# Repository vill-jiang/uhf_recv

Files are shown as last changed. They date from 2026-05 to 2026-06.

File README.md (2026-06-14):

# MT06xx UHF无线音频接收机项目

## 项目概述

这是一个基于STC8H1K17单片机+KT0656M的UHF无线话筒接收机项目,双通道接收,旋转编码器输入,菜单设置,OLED128x64输出.

## 项目起因

事情的起因是在小黄鱼捡垃圾捡到了便宜的UHF话筒,但是没有适配的接收机,所以把话筒拆开发现是 SH88F4051AX + KT0646M 的方案,刮了I2C的线路并且捕获了芯片初始化和设置通道的数据,计算得到了话筒的频率.

随后便了解到这个UHF方案已经有 xytoki 大佬探索过 https://github.com/xytoki/kt06xx 便开始的UHF接收机的复刻

https://oshwhub.com/xytoki/wmic-kt06 给了我很大的信心和真正的帮助,但是真正在实现的时候仍然踩坑不少.

## 项目特性

### 硬件特性
- **主控芯片**: STC8H1K17 (QFN-20超小封装)
- **无线芯片**: KT0656M (仅支持0x11版本)
- **显示**: 128x64 OLED屏幕I2C总线
- **输入**: 旋转编码器
- **音频输出**: I2S数字音频输出和模拟输出可选
- **双通道**: 支持A/B两个独立通道

### 软件特性
- **模块化设计**: 主界面和设置菜单分离设计
- **存储优化**: 提取大量固定数据到EEPROM
- **内存优化**: 自定义指令压缩代码量,自定义菜单存储结构提高可移植性
- **可移植性**: 尽可能与硬件平台解耦
- **嵌套菜单**: 理论上支持无限深度菜单导航

### 外观特征

|  |  |
| ---- | ---- |
| 正面装配图 | 背面装配图 |
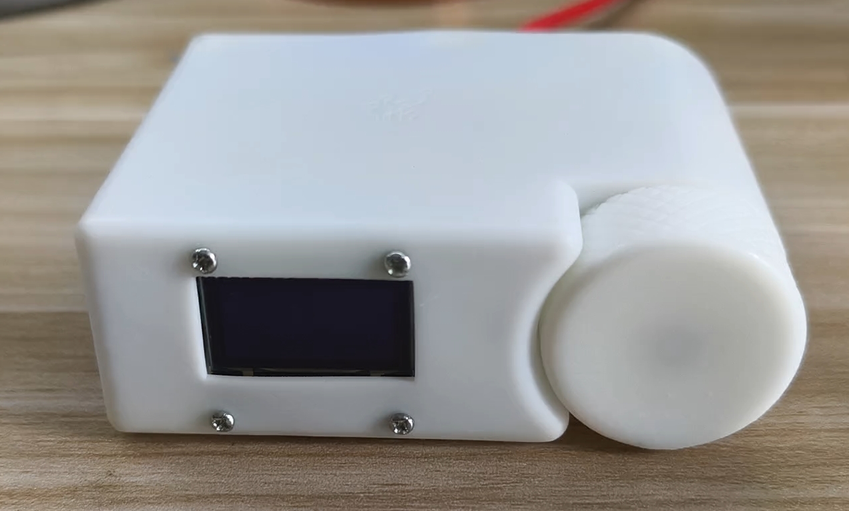
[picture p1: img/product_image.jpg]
实物图1
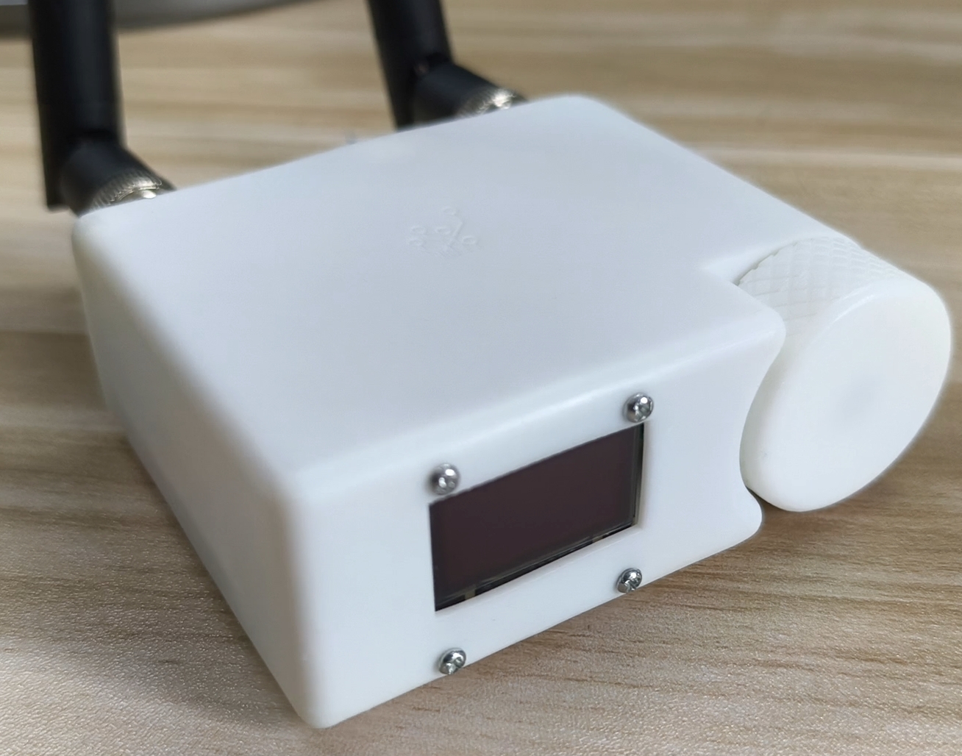
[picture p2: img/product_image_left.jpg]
实物图2
|  |  |

## 项目结构

## 技术实现

### 内存优化策略

#### EEPROM指令序列存储
由于STC8H1K17的Flash容量有限(17KB),项目采用创新的EEPROM指令序列存储方案：

- **指令编码**: 将复杂的芯片I2C初始化序列编码为紧凑的二进制格式
- **虚拟指令集**: 支持读/写/与/或/循环/延时等操作
- **运行时解释**: 通过`kt0656m_run_step_seq()`函数解释执行指令序列

**节省效果**: 将原本需要数千字节的驱动代码压缩到两百字节的指令序列

#### 菜单系统优化
- **LV编码字符串**: 所有代码都使用Length-Value-Zero编码存储字符串,节省字符串长度计算时间,降低屏幕渲染计算量
- **STC库优化**: 删除不必要的除法操作转为编译期确定,节省除法库链接占用Flash容量
- **局部变量合并**: 优化函数参数和局部变量使用

### 菜单系统设计

#### 主界面 (Home)
- 支持A/B双通道简易电平表动态显示
- 旋转编码器切换焦点：A设置 ↔ B设置 ↔ 关机 ↔ 空闲
- 上电关机,支持长按开关机

```
 __________________
│ A 600.100 MHz    │
│ ■■■■■■■□□□□□□    │
│                ╳ │
│ B 630.100 MHz    │
│ ■■■■■■■■■■□□□    │
 ‾‾‾‾‾‾‾‾‾‾‾‾‾‾‾‾‾‾
```

#### 设置菜单 (Menu)
- **条目类型**: 整数,字符串枚举,子菜单,返回
- **嵌套支持**: 理论支持无限级菜单深度
- **变更回调**: 设置结果联动逻辑

```
 _______________________      _______________________
│ ChA               1/5 │    │ ChA>EQ           1/16 │
│ --------------------- │    │ --------------------- │
│ <-                    │    │ <-                    │
│ ▪FreqKhz       600100 │    │ ▪EQ                ON │
│ ▪Vol               31 │    │ ▪25Hz               3 │
│ >EQ                -> │    │ ▪40Hz               3 │
│ >Echo              -> │    │ ▪63Hz               2 │
│ >Exciter           -> │    │ ▪100Hz              1 │
 ‾‾‾‾‾‾‾‾‾‾‾‾‾‾‾‾‾‾‾‾‾‾‾      ‾‾‾‾‾‾‾‾‾‾‾‾‾‾‾‾‾‾‾‾‾‾‾
```

## 编译和烧录

### 烧录配置

建议使用STC官方下载器下载二进制程序和EEPROM文件.

调试阶段如果需要使用PlatformIO的下载功能的话,由于PlatformIO的STC8H支持问题,需要修改如下配置：

1. 编辑`.platformio/platforms/intel_mcs51/boards/STC8H1K17.json`
2. 将`"stcgal_protocol"`改为`"stc8g"`
3. 主频设置为24MHz或者以下

### 内存使用情况
- **Flash**: 12914 Bytes + 4K Bytes EEPROM, 仅剩余 398 Bytes, 基本榨干芯片空间
- **RAM**: 128 Bytes DSEG + 12 Bytes OSEG + 140 Bytes SSEG + 369 Bytes XSEG

## 踩坑记录

### 2.1. 单片机选型失败(FLASH太小,XRAM在SDCC下不算好用)

偏爱小封装的原因选择了STC8H1K08的QFN-20,结果下载下来看KT0656M的示例代码直接傻眼,8K的FLASH完全不够,正式的程序还没写就已经超容量了,仔细裁剪函数才刚好能装下,但是已经写不了任何其它显示逻辑了.

所以就有了抽象I2C操作序列到EEPROM的办法,可以参见tools\gen_eeprom_bin.py的设计,直接把kt06xx的驱动代码减少了 2500+ 字节.外加显示字库,显示初始化,菜单项等数据放入EEPROM,真正做到了芯片存储全榨干.

这里的抽象很有意思,将所有的I2C操作抽象成读数据,改数据,写数据或判断循环三大步,每一步都规定了多种操作方法,极大简化了代码空间的占用,并且将设置逻辑移到了python代码中,有点类似于一套自定义高级语言的感觉了,也更方便大规模自定义下载了.

指令序列(CmdSeq)的整体结构如下,每条指令由操作码(OP)+可变长地址(ADDR)+可变长数据(DATA)组成,
解释器逐条读取执行,遇到 `OP_END(0x00)` 结束整个序列:

```
┌──────────────────── CmdSeq(Save in EEPROM) ────────────────────┐
│                                                                │
│  ┌── Cmd1 ──┐  ┌── Cmd2 ──┐        ┌── CmdN ──┐  ┌── End ──┐   │
│  │OP│ADDR│D │  │OP│ADDR│D │  ...   │OP│ADDR│D │  │  0x00   │   │
│  └─────────-┘  └──────────┘        └──────────┘  └─────────┘   │
│                                                                │
└────────────────────────────────────────────────────────────────┘
```

每条指令(Cmd)由1字节OP + 0到2字节可变长地址 + 0到2字节可变长数据组成,OP字节按位划分四个区域:

```
       ┌───────────┬────────────┬───────┬───────┬───────────┐
       │  bit[7:6] │  bit[5:4]  │ bit[3]│ bit[2]│  bit[1:0] │
       │  AddrMode │ Write/Loop │   Or  │  And  │    Read   │
       │           │ WriteRAM   │       │       │           │
       └───────────┴────────────┴───────┴───────┴───────────┘
```

**AddrMode(bit[7:6])** —— 地址字段编码,紧跟在OP字节之后:

```
┌────┬──────────────┬──────────────────────────────────────────────┐
│ 00 │ OP_ADDR_OLD  │ 不附加地址字节,沿用上一条指令的地址             │
│ 01 │ OP_ADDR_INC  │ 不附加地址字节,地址=上一条地址+1               │
│ 10 │ OP_ADDR_ONE  │ 追加1字节,只有低字节(ADDR_L),高字节是0         │
│ 11 │ OP_ADDR_TWO  │ 追加2字节,完整的ADDR_H + ADDR_L               │
└────┴──────────────┴──────────────────────────────────────────────┘
```

> 连续写相邻寄存器时用 `OP_ADDR_INC`,可省掉整个地址字段(节省2字节);
> 高位0x00寄存器用 `OP_ADDR_ONE_BYTE`,只保留低字节(节省1字节).

**Read/And/Or/Write/Loop** —— 每个位独立表示一个阶段动作,按 `Read → And → Or → Write/Loop` 顺序执行,消耗 DATA 区的字节:

```
 Read (bit[1:0])                    And (bit[2])             Or (bit[3])
┌────┬──────────────────────────┐   ┌───┬───────────────┐   ┌───┬───────────────┐
│ 01 │ Delay 1ms and read ADDR  │   │ 1 │ var &= DATA[i]│   │ 1 │ var |= DATA[i]│
│ 10 │ Read ADDR to var         │   └───┴───────────────┘   └───┴───────────────┘
│ 11 │ var = DATA[i++] (立即数) │
└────┴──────────────────────────┘

 Write/Loop (bit[5:4])
┌─────┬──────────────────────────────────────────────────────────────────┐
│ 01  │ OP_WRITE: Write var to ADDR                                      │
│ 10  │ OP_LOOP : if (var == DATA[i]) goto Read阶段重试(常用于轮询等待)    │
│ 11  │ OP_READ_RAM_WRITE : Write public[var] to ADDR                    │
└─────┴──────────────────────────────────────────────────────────────────┘
```

举例说明,以初始化序列中"设置晶振"这条指令为例:

```
原始C代码:  var = ReadI2C(0x0108); var &= 0x1F; var |= 0x40; WriteI2C(0x0108, var);

编码为:     0xDE  0x01  0x08  0x1F  0x40
           ────  ─────────── ────  ────
            OP    ADDR(TWO)  AND值 OR值
             │
         0xDE = 0b_11_01_1_1_10
                   │   │ │ │ └── 10    : 读 ADDR 到 var
                   │   │ │ └──── And=1 : var &= 0x1F
                   │   │ └────── Or =1 : var |= 0x40
                   │   └──────── 01    : 写回 var 到 ADDR
                   └──────────── 11    : 地址模式 TWO_BYTES,后随2B地址

执行流程:   ReadI2C(0x0108) → &=0x1F → |=0x40 → WriteI2C(0x0108, var)
            一条5字节指令 替代了 原本需要的多个C语句
```

更紧凑的例子(防啸叫设置中连续写 `0x026F → 0x0270 → 0x0271 → 0x0272`):

```
OP_ADDR_TWO | ... , 0x02, 0x6F, ..., SQUEAL_EN     ; 首条,带2B地址
OP_ADDR_INC | Read_ROM | Write   , SQUEAL_FFT      ; 只用1字节OP+1字节数据
OP_ADDR_INC | Read_ROM | Write   , SQUEAL_PMAX     ; 地址自动+1
OP_ADDR_INC | Read_ROM | Write   , SQUEAL_FDIFF    ; 地址自动+1
```

后面根据相同封装更换了STC8H1K17的QFN-20,17KB的FLASH加上上面的优化之后也是勉强够用,奉劝大家先看代码规模留足余量再选型.
另外,软件生态也非常重要,有复杂的外设还是建议直接使用ESP系列的芯片.

另外还有个小问题,由于8051的RAM的idata固定只有256字节,参见[这里](https://www.keil.com/support/man/docs/is51/is51_ov_extmemorylayout.asp),这里只是增加了1KB的xdata段来增大RAM空间,但是实际使用的时候还是比较麻烦,总是需要考虑声明的变量需要放在那里,后面干脆直接全放xdata了,所以代码重可以看到很多 __xdata 标记.

### 2.2. KT0656M版本差异(0x11和0x10)

[示例代码这里](https://github.com/xytoki/kt06xx/blob/18bf760dedeff7c1949583c3ed029dc3e3875e47/democode/KT0656M_demoboard/KT_WirelessMicRxdrv.c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)可以看到读了一个 FIRMWARE_VERSION 的寄存器需要强制判断是 `0x10`,刚开始完全无法启动.

逻辑分析仪抓波形才发现我买到的芯片这里是返回了`0x11`,于是直接去掉了这里的版本检查,但是看起来仍然无法正常跑,噪声非常大,有时候能匹配到频道声音还特别小.

这个时候首先开始怀疑是不是买到了假芯片了,后来想一想这个democode明显写了非常多的patch,并且datsheet还没到1.0版本,便试一试能否找到其它democode.

天无绝人之路,在国内某C开头的收费下载网站真找到了兼容 `0x10` 和 `0x11` 示例代码,去掉所有兼容逻辑之后代码还简单了非常多,也不需要在主循环内跑一个写寄存器的patch函数了,看起来是厂家在芯片的固件中内部修复了.也减轻了我这里存储的负担.

芯片固件的主要改动整理到下面了,通过 `KT_Bus_Read(0x010f, chipSel)` 读取固件版本号(0x10=a版本, 0x11=b版本),两个版本的差异如下:

| 差异点 | a版本 (0x10) | b版本 (0x11) |
| :---  | :---  | :---  |
| ① Init:<br>AFC控制 | AFC CTRL FSM disable<br>reg 0x010e &= 0xFE | AFC CTRL FSM enable<br>reg 0x010e \|= 0x01 |
| ② Tune:<br>RF中断使能 | rfamp_int_en = 0<br>tune前写 reg 0x0053 &= ~0x40 | 不操作<br>(芯片内部已修复)<br>使得Tune和FastTune等价 |
| ③ Tune:<br>PLL done后<br>温漂修复 | 需要手动执行:<br>· DSP_RST + PLL_SDM_RST<br>· Pll_Band_Cali(0, 255)<br>· PLL_Reset()<br>· LO_LOCK_DET_PD 保存/恢复<br>· locoarse_var_sel 重算<br>· SOFT_SNR_MUTE 条件清除 | 不需要<br>(芯片内部已修复温漂问题) |
| ④ Patch:<br>rfIntCtl() | 需要在主循环中持续调用<br>根据RF增益动态开关rfamp_int_en | 不需要<br>(芯片内部已修复) |
| ⑤ Patch:<br>pilotMuteRefresh() | 需要在主循环中持续调用<br>修复导频mute的bug<br>导频开启但未检测到时强制mute | 不需要<br>(芯片内部已修复) |
| ⑥ Patch:<br>snrMuteRefresh() | 需要在主循环中持续调用<br>修复SNR mute的bug<br>SNR低于阈值时强制soft mute | 不需要<br>(芯片内部已修复) |

总结: b版本(0x11)在芯片固件中修复了a版本的多个bug,
      省去了 Tune 中的温漂修复流程 和 主循环中的 Patch() 调用,
      代码量大幅减少,也更加稳定.

### 2.3. 天线设计问题

由于完全没有天线设计经验,第一个版本出来的声音总是有个高频的噪声,声音大的时候不明显,声音小就很刺耳,更换了电源和运放都不能解决,这是第一个版本测试天线的图片.

第二个版本保留了模拟和I2S可选输出,最终也只使用了I2S输出,并且直接使用了 xytoki 大佬的天线结构,再也没有底噪了.

在第二个版本PCB是模拟输出和I2S可选的,实际上增加外壳之后模拟输出效果也非常好,不想购买PCM芯片的可以尝试模拟输出.

有个[简单的网页](https://www.changpuak.ch/electronics/LumpedBalunCalculator.php)可以方便计算天线参数,需要知道天线的阻抗和芯片的阻抗.

### 2.4. PlatformIO无法直接烧录

STC8H1K系列的单片机在PlatformIO中会当作STC8H来使用stcgal_protocol烧录二进制,后面看了stcgal的代码才发现STC8G的protocol来兼容STC8H的[protocols](https://github.com/grigorig/stcgal/blob/master/stcgal/protocols.py)

```
protocol_database = [...
                    ("stc8g", r"STC8H1K\d\d$"),
                    ...]
```

最终通过修改.platformio\platforms\intel_mcs51\boards\STC8H1K08.json 中的 "stcgal_protocol" 字段值为 "stc8g" 才解决.

还发现另一个问题,最高只能设置成24M主频及以下才能烧录成功,并且设置后的频率并不是完全准确的,读出来总是有偏差,估计是因为stcgal只支持自定义任意主频,并不支持STC官方烧录器的预置主频协议,后续有空可以抓STC官方烧录器的UART波形在来看看能否在stcgal中修复.

### 2.5. 菜单设计

菜单系统是本项目软件层面的核心交互组件，负责管理OLED屏幕显示和旋转编码器操作。为了保证在STC8H1K17有限的Flash和RAM资源下能够运行一个功能完整的设置菜单，采用了多项优化存储的设计。

#### 2.5.1. 数据结构层次与存储位置

菜单系统由多个数据结构组成，层次如下:

UML图

根据每个数据结构是否需要在运行时修改，分别存放在EEPROM（__code）和RAM（__xdata）中：

```
┌────────────────────────── EEPROM (__code, 只读) ─────────────────────────┐
│                                                                          │
│  static_str_data[]  (字符串表, LV编码)                                    │
│  ┌─────────┬─┬─┬─┬──┬───────┬─┬─┬─┬─┬─┬─┬─┬──┐                           │
│  │ Len=3   │C│h│A│\0│ Len=7 │F│r│e│q│.│.│.│\0│ ...                       │
│  └─────────┴─┴─┴─┴──┴───────┴─┴─┴─┴─┴─┴─┴─┴──┘                           │
│             ▲                ▲                                           │
│             │                │                                           │
│        menu_item_t[].name  val_type_str_t.first_str                      │
│                                                                          │
│  static_val_type_data[]  (值类型描述表)                                   │
│  ┌────────────┬────────────┬────────────┬────────────┐                   │
│  │ cur_val_idx│ min_val    │ max_val    │ step_val   │ ...               │
│  └────────────┴────────────┴────────────┴────────────┘                   │
│       ▲                                                                  │
│       │                                                                  │
│  menu_item_t[].val_offset                                                │
│                                                                          │
│  static_menu_item_data[]  (菜单条目表)                                    │
│  ┌────────────┬────────────┬────────────┐                                │
│  │ type       │ name_offset│ val_offset │ ...                            │
│  └────────────┴────────────┴────────────┘                                │
│                                                                          │
└──────────────────────────────────────────────────────────────────────────┘

┌────────────────────────── RAM (__xdata, 可读写) ──────────────────────────┐
│                                                                          │
│  ch_a_val_list[] / ch_b_val_list[]  (实际值存储)                          │
│  ┌────────────┬────────────┬────────────┬────────────┐                   │
│  │ freq(4B)   │ vol(1B)    │ echo(1B)   │ ...        │                   │
│  └────────────┴────────────┴────────────┴────────────┘                   │
│       ▲                                                                  │
│       │                                                                  │
│  val_type_xxx_t.cur_val_idx                                              │
│                                                                          │
│  main_menu_def / sub_menu_def_register[]  (菜单状态)                      │
│  ┌────────────┬────────────┬────────────┬────────────┐                   │
│  │ name       │ state_bits │ cur_idx    │ first_...  │ ...               │
│  └────────────┴────────────┴────────────┴────────────┘                   │
│       ▲                                                                  │
│       │                                                                  │
│  menu_ctx_t.cur_menu / .root_menu                                        │
│                                                                          │
│  g_menu_ctx  (菜单上下文)                                                 │
│  ┌────────────┬────────────┬────────────┐                                │
│  │ root_menu  │ cur_menu   │ val_list   │                                │
│  └────────────┴────────────┴────────────┘                                │
│                                                                          │
└──────────────────────────────────────────────────────────────────────────┘
```

**存储位置设计原则**：

- **EEPROM (__code)**：存放编译后固定不变的数据（菜单条目定义、值类型描述、字符串表）。EEPROM紧凑,但是运行时修改。将这些只读数据放在此处可节省宝贵的RAM和Flash空间。

- **RAM (__xdata)**：存放运行时需要修改的数据：
  - `menu_def_t`：需要修改`state_bits`（脏标志）、`cur_idx`（当前选中项）、`first_show_idx`（滚动偏移）
  - `val_list`（ch_a/b_val_list）：需要修改实际设置值（频率、音量等）
  - `menu_ctx_t`：菜单上下文，跟踪当前菜单状态

- **为什么不用函数指针**：SDCC编译器对函数指针的间接调用优化效果很差，会产生大量DSEG（内部RAM）的临时变量溢出。菜单系统将不同条目类型的操作统一编码为`type`字段（0-4），在函数中通过`if/else if`分派。

#### 2.5.2. 菜单结构与数据分离设计

菜单系统采用"结构（状态）"与"数据（定义）"分离的设计：

```
┌─────────────── 编译时生成 (gen_eeprom_bin.py) ──────────────┐
│                                                            │
│  menu_static_str_map (Python dict)                         │
│         ↓ 生成                                             │
│  static_str_data[] (EEPROM)                                │
│                                                            │
│  menu_static_val_type_list (Python dict)                   │
│         ↓ 生成                                             │
│  static_val_type_data[] (EEPROM)                           │
│                                                            │
│  (自动计算)                                                │
│         ↓ 生成                                             │
│  static_menu_item_data[] (EEPROM)                          │
│                                                            │
└────────────────────────────────────────────────────────────┘
                                │
                                │ 偏移量引用
                                ▼
┌────────────────────── 运行时 (menu.c) ──────────────────────┐
│                                                            │
│  menu_def_t (RAM)                                          │
│  .name ───────────────────→ static_str_data[offset]        │
│  .first_item_idx[] ─────────→ menu_item_t[] (EEPROM)       │
│                                                            │
│  menu_item_t (EEPROM)                                      │
│  .type                                                     │
│  .name ───────────────────→ static_str_data[offset]        │
│  .val_offset ─────────────→ val_type_xxx_t (EEPROM)        │
│                                                            │
│  val_type_xxx_t (EEPROM)                                   │
│  .cur_val_idx ─────────────→ val_list[] (RAM)              │
│  .min_val, .max_val, .step_val                             │
│                                                            │
└────────────────────────────────────────────────────────────┘
```

**分离设计的优势**：

1. **节省RAM**：所有菜单定义数据（字符串、值类型描述、条目定义）都存储在EEPROM中，运行时只通过偏移量引用
2. **易于维护**：菜单定义集中在Python脚本中，修改菜单结构只需修改Python字典，无需手动计算偏移量
3. **支持A/B双通道共用**：通过不同的`val_list`（ch_a/b_val_list）和`root_name`，A/B通道可以共用同一套菜单定义

#### 2.5.3. 菜单条目类型

菜单系统支持4种条目类型：

```
┌────────────────┬────────────────────────────────────────────────────┐
│  类型          │  描述                                               │
├────────────────┼────────────────────────────────────────────────────┤
│ TYPE_BACK      │ 返回上级菜单（根菜单中表现为退出并保存）              │
│ TYPE_INT8      │ 8位整数编辑，支持min/max/step循环增减                │
│ TYPE_INT32     │ 32位整数编辑（用于频率设置，赫兹级精度）              │
│ TYPE_STRENUM   │ 字符串枚举（ON/OFF开关等），循环切换                  │
│ TYPE_SUBMENU   │ 嵌套子菜单，通过sub_menu_def_register跳转            │
└────────────────┴────────────────────────────────────────────────────┘
```

其中TYPE_INT8/TYPE_INT32/TYPE_STRENUM的min/max/step/cur_val_idx等元数据存储在EEPROM的`static_val_type_data`区，运行时通过`get_static_val_type()`宏读取。`cur_val_idx`指向RAM中的`val_list`数组，实际值存储在那里。

#### 2.5.4. 输入操作与显示刷新设计

菜单系统通过`menu_input()`处理输入事件，通过`menu_draw()`刷新显示。采用脏标志（dirty flag）机制避免不必要的全屏刷新：

```
            输入事件 (编码器+按键)                    显示刷新
                 │                                      │
                 ▼                                      ▼
┌────────────────────────────────────┐   ┌─────────────────────────────────┐
│  menu_input(&ctx, input)           │   │  menu_draw(&ctx)                │
│                                    │   │                                 │
│  input & MENU_INPUT_CW/CCW?        │   │  SWITCH_MENU dirty?             │
│       ├── 是 → 滚动条目/修改值      │   │       ├── 是 → 绘制标题行        │
│                                    │   │       └── 清除脏标志             │
│  input & MENU_INPUT_BTN_UP?        │   │                                 │
│       ├── 是 → 进入/退出编辑        │   │  MODIFY_MENU dirty?             │
│       ├── BACK → 返回/退出         │   │       ├── 是 → 绘制分数          │
│       ├── SUBMENU → 跳转子菜单     │   │       ├── 是 → 绘制条目列表       │
│       └── 其他 → 进入值选择模式     │   │       └── 清除脏标志             │
│                                   │   │                                  │
│  设置脏标志:                       │   │  MODIFY_DATA dirty?              │
│       ├── SWITCH_MENU (切换菜单)   │   │       └── 是 → 重绘当前值         │
│       ├── MODIFY_MENU (修改条目)   │   │                                  │
│       └── MODIFY_DATA (修改数据)   │   │  (无脏标志 → 跳过绘制)            │
└───────────────────────────────────┘   └──────────────────────────────────┘
                 │                                      │
                 └──────────────────────────────────────┘
                            脏标志驱动的状态更新
```

**输入事件定义** (与编码器直接对应，无需转换)：

- `MENU_INPUT_CW` (0x01)：顺时针旋转一格
- `MENU_INPUT_CCW` (0x02)：逆时针旋转一格
- `MENU_INPUT_BTN_DOWN` (0x04)：按键按下
- `MENU_INPUT_BTN_UP` (0x08)：按键松开
- `MENU_INPUT_BTN_LONG` (0x10)：按键长按（显示"Unsaved..."提示）
- `MENU_INPUT_BTN_LONG_UP` (0x20)：按键长按松开（退出不保存）

**显示刷新策略**：

- **标题行**：仅在`MENU_STATE_BITS_SWITCH_MENU`脏标志置位时重绘，绘制"面包屑标题+分割横线"两行
- **分数**：在`MENU_STATE_BITS_MODIFY_MENU`时更新右上角的"当前项/总数"指示
- **条目列表**：6行（MENU_ITEM_ROWS）条目区域，每次全量重绘。通过`first_show_idx`实现滚动窗口，当`cur_idx`超出可视范围时同步移动窗口

这种策略在6MHz主频的8051上依然能保持流畅的旋转编码器操作响应。

#### 2.5.5. 子菜单导航

子菜单通过`sub_menu_def_register[]`数组管理，最多支持`MENU_SUBMENU_MAX_IDX`个（当前3个：EQ、Echo、Exciter）。每个子菜单的条目列表存储在`__xdata`数组中，导航时：

1. 遇到SUBMENU条目 → `menu_def_register[条目.val_offset]`跳转到对应子菜单定义
2. 子菜单的`parent_menu`指回父菜单，形成双向链式结构
3. `menu_title_draw()`递归遍历`cur_menu → ... → root_menu`，构建面包屑导航标题（如 "ChA>EQ"）

标题的最大显示宽度受`MENU_MAX_FRAC_COLS`（8字符）和标题文本长度约束，超出部分会被覆盖清除。

## AI含量

| 功能点 | vibe coding | craft coding | 备注
| :---: | :---:  | :---: | :--- |
| STC库适配SDCC | 10% | 90% | 新建项目时还未开始使用AI,工作量也不大,仅仅使用AI生成了自动替换的python代码. |
| 字符串处理库 | 50% | 50% | AI总是根据传统的方法来处理,即使说明了需要省空间为主,也总是喜欢考虑常见的corner case. |
| 旋转编码器 | 95% | 5% | 对于常见的旋转编码器,AI能快速生成高效的处理代码,并且能根据空间和时间需求简化中断函数,人工仅做了测试和步进位数修改的工作. || KT06芯片库适配 | 10% | 90% | AI决策不够智能,总是花精力在无关的原始代码上,实际上很多代码都可以不迁移适配.即使人类要求必须要省空间,AI难以提供可以直接执行的省空间方案,但是当人类提出将I2C指令序列抽出到EEPROM,AI能够输出合适的python代码,但是需要人工检查和修改. |
| 主页 | 0% | 100% | 很难和AI描述如何设计一个主页,描述的工作量相当于人类直接实现的工作量 |
| 菜单 | 40% | 60% | AI能根据已有开源项目设计一个兼容性很高的的菜单系统,但是编译就超FLASH了,人类在其基础上删减了一些不必要的功能,并且提出了全局静态字符串概念固定数据存储到EEPROM的方法,AI能根据需求实现python代码. |
| 调试 | 0% | 100% | 暂时没有合适的方法能让AI闭环调试硬件的能力,也许增加摄像头和机械手可以? |
| 外观设计 | 30% | 70% | 让AI生成了几个版本的概念图,但是很难符合人类的审美和内心难以描述的需求,等到人类知道描述自己的需求之后,AI能快速理解并生成预览图. |
| 总结 | 0% | 100% | 人类能够准确的描述需求的情况下才能让AI帮助自己,否则AI只会做个全网搬运工,并且在本项目中AI总是忘记了需要省FLASH空间,是一种先发展后治理的思路,等到编译超空间了再去其他办法解决,实际上有很多办法(例如--model-large)已经尝试过了是无效的或者副作用太大. |

## 致谢

- **xytoki**: 提供了KT06xx系列的探索和开源代码及文档
- **STC官方**: 提供了完善的主控的开发资料和技术支持

## 许可证

完整许可证文本见 [LICENSE](./LICENSE) 文件。

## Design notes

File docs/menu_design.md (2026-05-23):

# UHF 接收机菜单系统设计文档

## 一、面临的问题

本项目运行在 **STC8H1K17** (8051 内核) 单片机上，主频 24MHz，资源极度受限：

| 约束 | 具体限制 |
|---|---|
| RAM (xdata) | 仅 1KB，所有全局变量共享 |
| ROM (code) | 17KB Flash，需存放程序 + 常量数据 |
| 栈深度 | 8051 idata 栈仅 128 字节 |
| 显示 | SSD1106 OLED 128×64，6×8 字体下仅 21 列 × 8 行 |
| 输入 | 单个旋转编码器（旋转 + 按键） |
| 菜单项数量 | 29 个菜单项，含 3 个子菜单，15 段 EQ 参数 |

### 核心矛盾

1. **ROM 空间紧张**：菜单的字符串、值范围描述等静态数据如果以 C 结构体硬编码，编译器会将其放入 code 段，但手动维护困难且容易出错。
2. **RAM 极度稀缺**：不能为每个菜单项分配独立的值存储结构体，否则 RAM 会迅速耗尽。
3. **多通道复用**：A/B 两个通道共享相同的菜单结构（频率范围不同除外），需要用最小代价实现通道切换。
4. **可维护性**：菜单项的增删改需要同步修改字符串表、值类型表、菜单项索引等多处数据，手动维护极易出错。

### 解决思路

采用 **"离线生成 + 运行时解释"** 的架构：

- **离线**：Python 脚本 (`gen_eeprom_bin.py`) 从声明式配置生成紧凑的二进制数据（字符串表、值类型表、菜单项表），烧录到 EEPROM/code 区。
- **运行时**：C 代码通过偏移量索引访问只读数据，用一个扁平的 `int8_t val_list[]` 数组存储所有可变值，实现数据与逻辑的彻底解耦。

---

## 二、整体架构

```
┌─────────────────────────────────────────────────────────────┐
│                    gen_eeprom_bin.py                        │
│  (声明式配置 → 二进制数据 → eeprom_bin_data.h/.c)             │
└──────────────────────────┬──────────────────────────────────┘
                           │ 生成
                           ▼
┌──────────────────────────────────────────────────────────────┐
│              EEPROM / Code 区 (只读)                         │
│  ┌───────────────┬────────────────────┬─────────────────────┐│
│  │static_str_data│static_val_type_data│static_menu_item_data││
│  │  (265 Bytes)  │   (118 Bytes)      │    (87 Bytes)       ││
│  └───────────────┴────────────────────┴─────────────────────┘│
└──────────────────────────┬───────────────────────────────────┘
                           │ 偏移量索引
                           ▼
┌─────────────────────────────────────────────────────────────┐
│                   menu.c 运行时引擎                          │
│  ┌────────────┐  ┌────────────┐  ┌──────────────────┐       │
│  │ menu_input │→ │ menu_draw  │→ │ menu_value_change│       │
│  └────────────┘  └────────────┘  └──────────────────┘       │
│         ↕                                    ↕              │
│  ┌────────────────────────────────────────────┐             │
│  │  val_list[MENU_VAL_DATA_LEN] (xdata RAM)   │             │
│  │  ch_a_val_list / ch_b_val_list (27 Bytes)  │             │
│  └────────────────────────────────────────────┘             │
└─────────────────────────────────────────────────────────────┘
```

---

## 三、各模块设计详解

### 3.1 静态字符串表 (`static_str_data`)

#### 存储格式

```
[len][char0][char1]...[charN][0x00]  ← 每个字符串
```

- `offset - 1` 处存放字符串长度（不含 `\0`）
- `offset` 处开始是实际字符数据，以 `\0` 结尾

#### 访问宏

```c
#define get_static_string(offset)     (static_str_data + (offset))
#define get_static_string_len(offset) (static_str_data[(offset) - 1])
```

#### 设计优点

- 字符串共享：多个菜单项可引用同一个字符串偏移（如 `FreqKhz` 被 A/B 频率共用）
- 零拷贝：直接返回 code 区指针给 OLED 驱动，无需 RAM 缓冲
- 编译期确定：所有 `STATIC_STR_xxx_OFFSET` 宏由 Python 自动生成

#### Python 生成逻辑

```python
menu_static_str_map = {
    'RETURN': '-',
    'PrefixChar': '<""">',   # 按 MENU_ITEM_TYPE_xxx 索引取前导字符
    'FreqKhz': 'FreqKhz',
    'Volume': 'Volume',
    ...
}
```

遍历字典，依次写入 `[len][data][0x00]`，记录每个字符串的起始偏移。

---

### 3.2 值类型描述表 (`static_val_type_data`)

每个菜单项的值约束信息紧凑排列在此表中，根据类型不同有不同的结构：

| 类型 | 结构体 | 字节数 | 字段说明 |
|---|---|---|---|
| INT8 | `val_type_int8_t` | 4 | `cur_val_idx`(1) + `min`(1) + `max`(1) + `step`(1) |
| INT32 | `val_type_int32_t` | 13 | `cur_val_idx`(1) + `min`(4) + `max`(4) + `step`(4) |
| STRENUM | `val_type_str_t` | 3 | `cur_val_idx`(1) + `first_str`(1) + `str_count`(1) |
| SUBMENU | 子菜单索引 | 1 | 指向 `sub_menu_def_register[]` 的索引 |

#### 关键字段 `cur_val_idx`

这是整个解耦设计的核心——它不存储值本身，而是存储 **值在 `val_list[]` 数组中的下标**。

```c
// 运行时读取值：
int8_t current_volume = val_list[val_ptr->cur_val_idx];  // cur_val_idx = 4
```

#### 访问宏

```c
#define get_static_val_type(type, offset) \
    ((const type __code *)(static_val_type_data + (offset)))
```

通过 `menu_item_t.val_offset` 定位到对应的值类型描述。

---

### 3.3 菜单项表 (`static_menu_item_data`)

每个菜单项固定 3 字节：

```
[type][name_offset][val_offset]
```

| 字段 | 大小 | 说明 |
|---|---|---|
| `type` | 1 Byte | `MENU_ITEM_TYPE_BACK/INT8/INT32/STRENUM/SUBMENU` |
| `name` | 1 Byte | 指向 `static_str_data` 的偏移 |
| `val_offset` | 1 Byte | 指向 `static_val_type_data` 的偏移 |

#### 访问宏

```c
#define get_static_menu_item(idx) \
    (((const menu_item_t __code *)static_menu_item_data) + (idx))
```

29 个菜单项仅占 87 字节 ROM。

---

### 3.4 菜单定义结构 (`menu_def_t`)

```c
typedef struct menu_def {
    menu_string_offset_t name;           // 菜单标题在字符串表中的偏移
    uint8_t state_bits;                  // 状态位（脏标志 + 选择模式）
    int8_t cur_idx;                      // 当前光标位置
    int8_t first_show_idx;              // 滚动窗口起始位置
    menu_item_idx_t __xdata *first_item_idx;  // 菜单项索引数组指针
    struct menu_def __xdata *parent_menu;     // 父菜单指针
    int8_t count;                        // 菜单项总数
} menu_def_t;
```

#### 状态位设计

```
bit7: MENU_STATE_BITS_MODIFY_DATA  - 数据被修改（用于判断是否需要保存）
bit6: MENU_STATE_BITS_MODIFY_MENU  - 菜单显示需要刷新
bit5: MENU_STATE_BITS_SWITCH_MENU  - 切换了菜单层级（需重绘标题）
bit0: MENU_STATE_BITS_CHOOSE_VALUE - 当前处于值编辑模式
```

这种位域设计将多个布尔状态压缩到 1 字节，极大节省 RAM。

---

### 3.5 菜单上下文 (`menu_ctx_t`)

```c
typedef struct {
    menu_def_t __xdata *root_menu;   // 根菜单（A通道或B通道）
    menu_def_t __xdata *cur_menu;    // 当前展示的菜单层级
    int8_t __xdata *val_list;        // 当前通道的值数组指针
} menu_ctx_t;
```

仅 6 字节 RAM（3 个指针），通过指针切换即可实现 A/B 通道复用：

```c
// 打开A通道菜单
menu_open(&g_menu_ctx, &main_menu_def, ch_a_val_list, STATIC_STR_CHA_OFFSET);
// 打开B通道菜单（复用同一个 main_menu_def）
menu_open(&g_menu_ctx, &main_menu_def, ch_b_val_list, STATIC_STR_CHB_OFFSET);
```

---

### 3.6 EEPROM 数据与用户变量的解耦机制

这是本设计最核心的创新点：

```
┌────────────────────────────────┐     ┌──────────────────────────┐
│   EEPROM / Code 区 (只读)      │     │   xdata RAM (可读写)      │
│                                │     │                          │
│  val_type_int8_t {             │     │  ch_a_val_list[27] = {   │
│    cur_val_idx = 4,  ──────────┼──┐  │    [0..3]: freq_a (int32)│
│    min = 0,                    │  │  │    [4]: volume           │
│    max = 31,                   │  └──┼──► [5]: echo_sw          │
│    step = 1                    │     │    [6]: echo_ratio       │
│  }                             │     │    ...                   │
│                                │     │    [26]: eq_16khz        │
└────────────────────────────────┘     │  }                       │
                                       └──────────────────────────┘
```

#### 解耦原则

1. **只读描述** 存放在 code 区：值的范围、步进、显示名称等元数据
2. **可变数据** 存放在 xdata RAM：一个扁平的 `int8_t` 数组
3. **桥梁**：`cur_val_idx` 字段将两者关联——它告诉运行时引擎"去 `val_list` 的第几个字节读/写当前值"

#### 优势

- **零耦合**：增删菜单项只需修改 Python 配置，不影响 C 运行时代码
- **极省 RAM**：27 字节存储所有通道参数，A/B 通道各一份共 54 字节
- **类型安全**：INT32 类型的值占 4 字节（从 `val_list[0]` 开始），INT8 类型占 1 字节，通过 `cur_val_idx` 精确定位
- **通道隔离**：切换通道只需更换 `val_list` 指针，菜单结构完全复用

#### 值修改流程

```c
// menu_value_change() 中：
// 1. 从 code 区读取值描述
const val_type_int8_t __code *val_ptr = get_static_val_type(val_type_int8_t, item_ptr->val_offset);
// 2. 通过 cur_val_idx 定位到 RAM 中的实际值
int8_t *p_val = &val_list[val_ptr->cur_val_idx];
// 3. 在 min/max/step 约束下循环增减
int8_cicle(p_val, val_ptr->min_val, val_ptr->max_val, val_ptr->step_val, direction);
```

---

### 3.7 输入系统设计

#### 编码器事件定义

```c
#define ENCODER_EVT_CW          0x01    // 顺时针
#define ENCODER_EVT_CCW         0x02    // 逆时针
#define ENCODER_EVT_BTN_DOWN    0x04    // 按下
#define ENCODER_EVT_BTN_UP      0x08    // 松开
#define ENCODER_EVT_BTN_LONG    0x10    // 长按
#define ENCODER_EVT_BTN_LONG_UP 0x20    // 长按松开
```

#### 关键设计：编码器事件与菜单输入统一

菜单系统的 `MENU_INPUT_xxx` 宏与编码器事件值完全一致，避免了转换开销：

```c
#define MENU_INPUT_CW    0x01   // == ENCODER_EVT_CW
#define MENU_INPUT_CCW   0x02   // == ENCODER_EVT_CCW
#define MENU_INPUT_BTN_UP 0x08  // == ENCODER_EVT_BTN_UP
```

#### 状态机流转

```
         ┌──────────────────────────────────────┐
         │           APP_STATE_HOME             │
         │  旋转: 切换焦点 (W→A→B→Power→W)       │
         │  按键: 进入菜单                       │
         └───────────────┬──────────────────────┘
                         │ BTN_UP (焦点在A或B)
                         ▼
         ┌──────────────────────────────────────┐
         │           APP_STATE_MENU             │
         │  旋转: 移动光标 / 修改值               │
         │  按键: 进入子菜单 / 选择值 / 返回      │
         └───────────────┬──────────────────────┘
                         │ 返回到根菜单的 BACK 项
                         ▼
                   回到 APP_STATE_HOME
```

---

### 3.8 显示绘制设计

#### 脏标志驱动的局部刷新

为了减少 I2C 通信量，采用脏标志位控制刷新粒度：

| 标志 | 触发条件 | 刷新范围 |
|---|---|---|
| `SWITCH_MENU` | 切换菜单层级 | 重绘标题栏 |
| `MODIFY_MENU` | 任何菜单操作 | 重绘项目列表 + 分数指示 |
| `HOME_STATUS_BIT_INPUT_DIRTY` | 主界面输入 | 重绘频率和焦点 |
| `HOME_STATUS_BIT_SWITCH_DIRTY` | 页面切换 | 全屏清除 |

#### 菜单绘制布局

```
行0: [标题>子标题]          [cur_idx/count]
行1: [#####################]  ← 分割线
行2: ["Volume              31]  ← 菜单项（前缀+名称+值）
行3: [>EQ                  ->]
行4: [>Echo                ->]
行5: [>Exciter             ->]
行6:
行7:
```

- 前缀字符由 `PrefixChar` 字符串按类型索引：`<` = BACK, `"` = INT8/INT32, `"` = STRENUM, `>` = SUBMENU
- 反显（黑底白字）表示当前选中项或值编辑模式

---

### 3.9 Python 代码生成工具 (`gen_eeprom_bin.py`)

#### 输入：声明式配置

```python
menu_static_val_type_list = {
    'Volume': (MENU_ITEM_TYPE_INT8, 'Volume', [4, 0, 31, 1]),
    #          类型                  显示名称    [val_idx, min, max, step]
    'EQ_SUB': (MENU_ITEM_TYPE_SUBMENU, 'EQ', None),
}
```

#### 输出

1. `eeprom_data.bin` — 烧录到 EEPROM 的二进制文件
2. `src/eeprom_bin_data.h` — 所有偏移量宏定义 + extern 声明
3. `src/eeprom_bin_data.c` — 指针常量定义（基于 `MOVC_ShiftAddress`）

#### 自动化保证一致性

修改菜单配置后只需重新运行 Python 脚本，所有索引、偏移量、长度宏自动更新，C 代码无需任何改动。

---

## 四、子菜单机制

### 子菜单注册表

```c
menu_def_t __xdata sub_menu_def_register[MENU_SUBMENU_MAX_IDX];
```

每个子菜单通过 `parent_menu` 指针形成准双向链表结构(实际只存储了子到父指针,父到子采用注册表偏移实现)，支持多级嵌套。当前实现了 3 个子菜单：

| 索引 | 名称 | 包含项目 |
|---|---|---|
| 0 | EQ | 开关 + 15 段频率增益 |
| 1 | Echo | 开关 + 混响比 + 延迟 |
| 2 | Exciter | 开关 + 奇次谐波 + 偶次谐波 |

### 进入/退出逻辑

```c
// 进入子菜单
ctx->cur_menu = get_sub_menu_def_ptr(item_ptr->val_offset);
init_menu_start_data(ctx->cur_menu);

// 退出子菜单
ctx->cur_menu = ctx->cur_menu->parent_menu;
```

---

## 五、未来提升建议

### 5.1 菜单项动态可见性

某些菜单项应根据开关状态隐藏（如 EQ 关闭时隐藏 15 段频率调节）。可在 `menu_item_t` 中增加 1 字节的 `visible_condition` 字段，指向 `val_list` 中的开关值。

### 5.2 值变更回调

当前值修改后没有立即通知硬件驱动。建议增加回调机制：

```c
typedef void (*val_change_cb_t)(cur_val_idx_t idx, int8_t new_val);
```

在 `menu_value_change()` 末尾调用回调，实时下发参数到 KT0656M 芯片。

### 5.3 长按快速调节

对于 INT32 类型（如频率 740150~769850，步进 10），旋转一圈仅改变 40，调满需要旋转 ~75 圈。建议：

- 长按 + 旋转时自动加大步进（如 ×10 或 ×100）
- 或增加"粗调/细调"模式切换

### 5.4 撤销/恢复功能

在进入菜单时备份 `val_list`（仅 27 字节），若用户选择"取消"则恢复备份，避免误操作。

### 5.5 菜单项排序与分组优化

当前菜单项的 `val_list` 索引是手动分配的。可在 Python 脚本中自动按类型紧凑排列（INT32 对齐到 4 字节边界），进一步减少 `MENU_VAL_DATA_LEN`。

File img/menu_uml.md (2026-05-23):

```plantuml
@startuml
skinparam classAttributeIconSize 0
skinparam linetype ortho

title menu.h 结构体关系图

' ===== 类型别名 =====
class "menu_string_offset_t" as MSO {
  uint8_t
  --
  索引到全局字符串表
  0=空字符串, 1-255=对应索引
}

class "cur_val_idx_t" as CVI {
  uint8_t
  --
  索引到菜单数据区(val_list)
}

class "val_type_offset_t" as VTO {
  uint8_t
  --
  索引到全局静态val_type_xxx_t
}

class "menu_item_idx_t" as MII {
  uint8_t
  --
  索引到全局静态menu_item_t
}

' ===== 值类型结构体 =====
class "val_type_int32_t" as VTI32 {
  +cur_val_idx : cur_val_idx_t
  +min_val : int32_t
  +max_val : int32_t
  +step_val : int32_t
  --
  val_list中占2字节
}

class "val_type_int8_t" as VTI8 {
  +cur_val_idx : cur_val_idx_t
  +min_val : int8_t
  +max_val : int8_t
  +step_val : int8_t
  --
  val_list中占1字节
}

class "val_type_str_t" as VTS {
  +cur_val_idx : cur_val_idx_t
  +first_str : menu_string_offset_t
  +str_count : int8_t
  --
  字符串枚举(含ON/OFF)
  val_list中占1字节
}

' ===== 菜单条目 =====
class "menu_item_t" as MI {
  +type : uint8_t
  +name : menu_string_offset_t
  +val_offset : val_type_offset_t
  --
  type决定val_offset指向:
  BACK(0) / INT8(1) / INT32(2)
  STRENUM(3) / SUBMENU(4)
}

' ===== 菜单定义 =====
class "menu_def_t" as MD {
  +name : menu_string_offset_t
  +state_bits : uint8_t
  +cur_idx : int8_t
  +first_show_idx : int8_t
  +first_item_idx : menu_item_idx_t*
  +parent_menu : menu_def_t*
  +count : int8_t
}

' ===== 菜单上下文 =====
class "menu_ctx_t" as MC {
  +root_menu : menu_def_t*
  +cur_menu : menu_def_t*
  +val_list : int8_t*
}

' ===== 关系 =====

' val_type 使用 cur_val_idx_t 索引 val_list
VTI32 --> CVI : cur_val_idx
VTI8 --> CVI : cur_val_idx
VTS --> CVI : cur_val_idx

' val_type_str_t 使用字符串偏移
VTS --> MSO : first_str

' menu_item_t 的关系
MI --> MSO : name
MI --> VTO : val_offset

' val_type_offset_t 可指向三种值类型
VTO ..> VTI8 : 当type=INT8
VTO ..> VTI32 : 当type=INT32
VTO ..> VTS : 当type=STRENUM

' menu_def_t 的关系
MD --> MSO : name
MD --> MII : first_item_idx[count]
MD --> MD : parent_menu\n(自引用/树形结构)

' menu_item_idx_t 索引 menu_item_t
MII ..> MI : 索引到

' menu_ctx_t 的关系
MC --> MD : root_menu
MC --> MD : cur_menu
MC --> CVI : val_list\n(int8_t数组)

@enduml
```

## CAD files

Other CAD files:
box/BoxShell.STEP
box/Btn.STEP
box/BoxFront.STEP

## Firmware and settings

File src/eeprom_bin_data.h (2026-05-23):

#ifndef _EEPROM_CODE_DATA_H_
#define _EEPROM_CODE_DATA_H_

#include "config.h"

extern const uint8_t __code * __xdata ssd1106_init_sequence;
#define SSD1106_INIT_SEQUENCE_LEN (26)

extern const uint8_t __code * __xdata ssd1106_font6x8;
#define SSD1106_FONT6X8_LEN (552)

extern const uint8_t __code * __xdata ssd1106_font8x16;
#define SSD1106_FONT8X16_LEN (1520)

extern const uint8_t __code * __xdata ssd1106_power_icon_16x16;
#define SSD1106_POWER_ICON_16X16_LEN (32)

extern const uint8_t __code * __xdata kt0656m_v11_init_seq;
#define KT0656M_V11_INIT_SEQ_LEN (142)

extern const uint8_t __code * __xdata kt0656m_v11_sai_init_master_seq;
#define KT0656M_V11_SAI_INIT_MASTER_SEQ_LEN (13)

extern const uint8_t __code * __xdata kt0656m_v11_sai_init_slave_seq;
#define KT0656M_V11_SAI_INIT_SLAVE_SEQ_LEN (20)

extern const uint8_t __code * __xdata kt0656m_v11_tune;
#define KT0656M_V11_TUNE_LEN (27)

extern const uint8_t __code * __xdata start_icon_bmp;
#define START_ICON_BMP_LEN (416)

extern const uint8_t __code * __xdata static_str_data;
#define STATIC_STR_DATA_LEN (311)

extern const uint8_t __code * __xdata static_val_type_data;
#define STATIC_VAL_TYPE_DATA_LEN (118)

extern const uint8_t __code * __xdata static_menu_item_data;
#define STATIC_MENU_ITEM_DATA_LEN (87)

#define PERSISTENT_DATA_SECTOR_START (0x0E00)
extern const uint8_t __code * __xdata default_data_channel_a;
#define DEFAULT_DATA_CHANNEL_A_LEN (27)

extern const uint8_t __code * __xdata default_data_channel_b;
#define DEFAULT_DATA_CHANNEL_B_LEN (27)

#define START_ICON_X0 (38)
#define START_ICON_Y0 (0)
#define START_ICON_X1 (90)
#define START_ICON_Y1 (8)
// call by: ssd1106_draw_bmp(START_ICON_X0, START_ICON_Y0, START_ICON_X1, START_ICON_Y1, start_icon_bmp);

// Static Static String Offsets in static_str_data, offset-1 is the string length without the null terminator, can be used for string retrieval
#define STATIC_STR_RETURN_OFFSET (1)
#define STATIC_STR_PREFIXCHAR_OFFSET (4)
#define STATIC_STR_SUBMENU_OFFSET (11)
#define STATIC_STR_OFF_OFFSET (15)
#define STATIC_STR_ON_OFFSET (20)
#define STATIC_STR_CHA_OFFSET (24)
#define STATIC_STR_CHB_OFFSET (29)
#define STATIC_STR_FREQKHZ_OFFSET (34)
#define STATIC_STR_VOLUME_OFFSET (43)
#define STATIC_STR_ECHO_OFFSET (51)
#define STATIC_STR_ECHORATIO_OFFSET (57)
#define STATIC_STR_ECHODELAY_OFFSET (68)
#define STATIC_STR_EXCITER_OFFSET (79)
#define STATIC_STR_EXCITERODD_OFFSET (88)
#define STATIC_STR_EXCITEREVEN_OFFSET (100)
#define STATIC_STR_EQ_OFFSET (113)
#define STATIC_STR_25HZ_OFFSET (117)
#define STATIC_STR_40HZ_OFFSET (123)
#define STATIC_STR_63HZ_OFFSET (129)
#define STATIC_STR_100HZ_OFFSET (135)
#define STATIC_STR_160HZ_OFFSET (142)
#define STATIC_STR_250HZ_OFFSET (149)
#define STATIC_STR_400HZ_OFFSET (156)
#define STATIC_STR_630HZ_OFFSET (163)
#define STATIC_STR_1KHZ_OFFSET (170)
#define STATIC_STR_1_6KHZ_OFFSET (176)
#define STATIC_STR_2_5KHZ_OFFSET (184)
#define STATIC_STR_4KHZ_OFFSET (192)
#define STATIC_STR_6_3KHZ_OFFSET (198)
#define STATIC_STR_10KHZ_OFFSET (206)
#define STATIC_STR_16KHZ_OFFSET (213)
#define STATIC_STR_CLEAR_OFFSET (220)
#define STATIC_STR_LINE_OFFSET (243)
#define STATIC_STR_SAVING_OFFSET (266)
#define STATIC_STR_UNSAVED_OFFSET (289)

// Menu Item Indices, Multiple defines for easy access
#define MENU_ITEM_RETURN_IDX (0)
#define MENU_ITEM_AFREQKHZ_IDX (1)
#define MENU_ITEM_BFREQKHZ_IDX (2)
#define MENU_ITEM_VOLUME_IDX (3)
#define MENU_ITEM_ECHO_IDX (4)
#define MENU_ITEM_ECHORATIO_IDX (5)
#define MENU_ITEM_ECHODELAY_IDX (6)
#define MENU_ITEM_EXCITER_IDX (7)
#define MENU_ITEM_EXCITERODD_IDX (8)
#define MENU_ITEM_EXCITEREVEN_IDX (9)
#define MENU_ITEM_EQ_IDX (10)
#define MENU_ITEM_25HZ_IDX (11)
#define MENU_ITEM_40HZ_IDX (12)
#define MENU_ITEM_63HZ_IDX (13)
#define MENU_ITEM_100HZ_IDX (14)
#define MENU_ITEM_160HZ_IDX (15)
#define MENU_ITEM_250HZ_IDX (16)
#define MENU_ITEM_400HZ_IDX (17)
#define MENU_ITEM_630HZ_IDX (18)
#define MENU_ITEM_1KHZ_IDX (19)
#define MENU_ITEM_1_6KHZ_IDX (20)
#define MENU_ITEM_2_5KHZ_IDX (21)
#define MENU_ITEM_4KHZ_IDX (22)
#define MENU_ITEM_6_3KHZ_IDX (23)
#define MENU_ITEM_10KHZ_IDX (24)
#define MENU_ITEM_16KHZ_IDX (25)
#define MENU_ITEM_EQ_SUB_IDX (26)
#define MENU_ITEM_ECHO_SUB_IDX (27)
#define MENU_ITEM_EXCITER_SUB_IDX (28)

#define MENU_VAL_DATA_LEN (27)

#define MENU_SUBMENU_MAX_IDX (3)
#define MENU_SUBMENU_EQ_IDX (0)
#define MENU_SUBMENU_ECHO_IDX (1)
#define MENU_SUBMENU_EXCITER_IDX (2)

#endif

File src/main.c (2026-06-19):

#include "STC8G_H_Delay.h"
#include "STC8G_H_GPIO.h"
#include "STC8G_H_Switch.h"
#include "STC8G_H_I2C.h"
#include "STC8G_H_EEPROM.h"
#include "STC8G_H_UART.h"
#include "kt0656m_v11_drv.h"
#include "ssd1106_oled.h"
#include "ws2812b_rgb.h"
#include "use_isr.h"
#include "string_lib.h"
#include "encoder.h"
#include "home.h"
#include "menu.h"

extern encoder_t __xdata g_encoder;

#define POWER_OFF_FLAG (1)
#define POWER_ON_NEED_CNT (2)
uint8_t __xdata mcu_power_off = POWER_OFF_FLAG;  // 刚开始就是关机状态
uint8_t __xdata mcu_power_on_cnt = 0;

// 重启之后只需要执行一次的初始化
void base_initialize(void) {
    // menu_def_protect_after = 0x55;
I2C_InitTypeDef __xdata i2c_init = {
    .I2C_Speed = (MAIN_Fosc / 2 / (400000UL * 2 + 4)), // 400kHz
    .I2C_Enable = ENABLE,
    .I2C_Mode = I2C_Mode_Master,
    .I2C_MS_WDTA = DISABLE
};
COMx_InitDefine __xdata uart_init = {
    .UART_Mode = UART_8bit_BRTx,
    .UART_BRT_Use = BRT_Timer1,
    .UART_BaudRate = (65536UL - (((MAIN_Fosc / 115200UL) + 2) / 4UL)),  // 115200
    .Morecommunicate = DISABLE,
    .UART_RxEnable = ENABLE,
    .BaudRateDouble = DISABLE
};
    EAXSFR();
    P0M0 = 0x00;
    P0M1 = 0x00;
    P1M0 = 0x00;
    P1M1 = 0x00;
    P2M0 = 0x00;
    P2M1 = 0x00;
    P3M0 = 0x00;
    P3M1 = 0x00;
    P4M0 = 0x00;
    P4M1 = 0x00;
    P5M0 = 0x00;
    P5M1 = 0x00;
    P3_MODE_IN_HIZ(GPIO_Pin_6 | GPIO_Pin_7);
    P3_PULL_UP_ENABLE(GPIO_Pin_0 | GPIO_Pin_1);
    P3_MODE_IN_HIZ(GPIO_Pin_0 | GPIO_Pin_2 | GPIO_Pin_3 | GPIO_Pin_4);
    P1_PULL_UP_ENABLE(GPIO_Pin_4 | GPIO_Pin_5);
    P3_PULL_UP_ENABLE(GPIO_Pin_2 | GPIO_Pin_3 | GPIO_Pin_4);
    I2C_SW(I2C_P14_P15);
    //设定掉电唤醒时钟约为0.5秒钟
    WKTCL = 0xE7;
    WKTCH = 0x83;
    // 关闭音频输出和无线芯片
    PCM_MUTE_PIN = 0;
    KT0656M_CHIP_EN_AM = 0;
    KT0656M_CHIP_EN_BM = 0;

    I2C_Init(&i2c_init);
    ssd1106_init();
    ssd1106_fillscreen(0);
    // UART初始化X
    UART1_SW(UART1_SW_P30_P31);
    UART_Configuration(UART1, &uart_init);
    TX1_write2buff('X');
    ES = 1;
    EA = 1;
    // 关灯
    send_color(0, 0, 0);
    send_color(0, 0, 0);
    send_rst();
}
// 软关机之后仍需执行的初始化
void soft_initialize(void) {
    home_init(&g_home_ctx);
    kt0656m_init();
    // 关灯
    send_color(0, 0, 0);
    send_color(0, 0, 0);
    send_rst();
}
// 软关机
void soft_shutdown(void) {
    mcu_power_off = POWER_OFF_FLAG;
    mcu_power_on_cnt = 0;
    // 关闭音频输出和无线芯片
    PCM_MUTE_PIN = 0;
    KT0656M_CHIP_EN_AM = 0;
    KT0656M_CHIP_EN_BM = 0;
    // 清屏
    ssd1106_fillscreen(0);
    // 关灯
    send_color(0, 0, 0);
    send_color(0, 0, 0);
    send_rst();
}
// 软开机
void soft_shutdown_tick(void) {
    if (mcu_power_off == POWER_OFF_FLAG) {
        if (!ENC_PIN_BTN) {
            mcu_power_on_cnt++;
        } else {
            mcu_power_on_cnt = 0;
        }
        if (mcu_power_on_cnt >= POWER_ON_NEED_CNT) {  // 开机
            mcu_power_off = 0;
            mcu_power_on_cnt = 0;
            soft_initialize();
        } else {
            PCON = 0x02;  // MCU进入掉电模式
        }
    }
}

int main(void) {
    uint8_t __xdata color[3] = {0}, last_rx_cnt = 0;
    uint8_t __xdata draw_event = 0;

    base_initialize();

    while (1) {
        soft_shutdown_tick();
        if (mcu_power_off == POWER_OFF_FLAG) {
            continue;
        }
        draw_event = home_input(&g_home_ctx);
        if (draw_event == HOME_INPUT_EVENT_POWER_OFF_CONFIRM) {
            soft_shutdown();  // 关机
            continue;
        } else if (draw_event == HOME_INPUT_EVENT_CHANGE_DATA_A) {
            kt0656m_current_addr = KT0656M_ADDR_A;
        } else if (draw_event == HOME_INPUT_EVENT_CHANGE_DATA_B) {
            kt0656m_current_addr = KT0656M_ADDR_B;
        }
        if (draw_event != HOME_INPUT_EVENT_NONE) {
            kt0656m_set_echo_eq();
            kt0656m_tune();
        }
        kt0656m_current_addr = KT0656M_ADDR_A;
        kt0656m_get_freq(&(g_home_ctx.frequency_a));
        g_home_ctx.af_data = kt0656m_get_af();
        kt0656m_current_addr = KT0656M_ADDR_B;
        kt0656m_get_freq(&(g_home_ctx.frequency_b));
        g_home_ctx.af_data |= (kt0656m_get_af() << 4);
        home_draw(&g_home_ctx);
        send_color(g_home_ctx.af_data & 0xF0, 0, 0);
        send_color(g_home_ctx.af_data << 4, 0, 0);
        send_rst();
        delay_ms(1);
    }
}

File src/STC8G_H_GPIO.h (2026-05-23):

/*---------------------------------------------------------------------*/
/* --- STC MCU Limited ------------------------------------------------*/
/* --- STC 1T Series MCU Demo Programme -------------------------------*/
/* --- Mobile: (86)13922805190 ----------------------------------------*/
/* --- Fax: 86-0513-55012956,55012947,55012969 ------------------------*/
/* --- Tel: 86-0513-55012928,55012929,55012966 ------------------------*/
/* --- Web: www.STCAI.com ---------------------------------------------*/
/* --- BBS: www.STCAIMCU.com  -----------------------------------------*/
/* --- QQ:  800003751 -------------------------------------------------*/
/* 如果要在程序中使用此代码,请在程序中注明使用了STC的资料及程序            */
/*---------------------------------------------------------------------*/

#ifndef __STC8G_H_GPIO_H
#define __STC8G_H_GPIO_H

#include "config.h"

// 屏蔽能节省代码大小
// 大约每个180Byte的代码体积
// #define GPIO_P0   0  //
#define GPIO_P1   1
// #define GPIO_P2   2
#define GPIO_P3   3
// #define GPIO_P4   4
// #define GPIO_P5   5
// #define GPIO_P6   6
// #define GPIO_P7   7

//========================================================================
//                            端口模式设置
//========================================================================
//准双向口
#define  P0_MODE_IO_PU(Pin)    P0M1 &= ~(Pin), P0M0 &= ~(Pin);
#define  P1_MODE_IO_PU(Pin)    P1M1 &= ~(Pin), P1M0 &= ~(Pin);
#define  P2_MODE_IO_PU(Pin)    P2M1 &= ~(Pin), P2M0 &= ~(Pin);
#define  P3_MODE_IO_PU(Pin)    P3M1 &= ~(Pin), P3M0 &= ~(Pin);
#define  P4_MODE_IO_PU(Pin)    P4M1 &= ~(Pin), P4M0 &= ~(Pin);
#define  P5_MODE_IO_PU(Pin)    P5M1 &= ~(Pin), P5M0 &= ~(Pin);
#define  P6_MODE_IO_PU(Pin)    P6M1 &= ~(Pin), P6M0 &= ~(Pin);
#define  P7_MODE_IO_PU(Pin)    P7M1 &= ~(Pin), P7M0 &= ~(Pin);
//高阻输入
#define  P0_MODE_IN_HIZ(Pin)   P0M1 |= (Pin), P0M0 &= ~(Pin);
#define  P1_MODE_IN_HIZ(Pin)   P1M1 |= (Pin), P1M0 &= ~(Pin);
#define  P2_MODE_IN_HIZ(Pin)   P2M1 |= (Pin), P2M0 &= ~(Pin);
#define  P3_MODE_IN_HIZ(Pin)   P3M1 |= (Pin), P3M0 &= ~(Pin);
#define  P4_MODE_IN_HIZ(Pin)   P4M1 |= (Pin), P4M0 &= ~(Pin);
#define  P5_MODE_IN_HIZ(Pin)   P5M1 |= (Pin), P5M0 &= ~(Pin);
#define  P6_MODE_IN_HIZ(Pin)   P6M1 |= (Pin), P6M0 &= ~(Pin);
#define  P7_MODE_IN_HIZ(Pin)   P7M1 |= (Pin), P7M0 &= ~(Pin);
//漏极开路
#define  P0_MODE_OUT_OD(Pin)   P0M1 |= (Pin), P0M0 |= (Pin);
#define  P1_MODE_OUT_OD(Pin)   P1M1 |= (Pin), P1M0 |= (Pin);
#define  P2_MODE_OUT_OD(Pin)   P2M1 |= (Pin), P2M0 |= (Pin);
#define  P3_MODE_OUT_OD(Pin)   P3M1 |= (Pin), P3M0 |= (Pin);
#define  P4_MODE_OUT_OD(Pin)   P4M1 |= (Pin), P4M0 |= (Pin);
#define  P5_MODE_OUT_OD(Pin)   P5M1 |= (Pin), P5M0 |= (Pin);
#define  P6_MODE_OUT_OD(Pin)   P6M1 |= (Pin), P6M0 |= (Pin);
#define  P7_MODE_OUT_OD(Pin)   P7M1 |= (Pin), P7M0 |= (Pin);
//推挽输出
#define  P0_MODE_OUT_PP(Pin)   P0M1 &= ~(Pin), P0M0 |= (Pin);
#define  P1_MODE_OUT_PP(Pin)   P1M1 &= ~(Pin), P1M0 |= (Pin);
#define  P2_MODE_OUT_PP(Pin)   P2M1 &= ~(Pin), P2M0 |= (Pin);
#define  P3_MODE_OUT_PP(Pin)   P3M1 &= ~(Pin), P3M0 |= (Pin);
#define  P4_MODE_OUT_PP(Pin)   P4M1 &= ~(Pin), P4M0 |= (Pin);
#define  P5_MODE_OUT_PP(Pin)   P5M1 &= ~(Pin), P5M0 |= (Pin);
#define  P6_MODE_OUT_PP(Pin)   P6M1 &= ~(Pin), P6M0 |= (Pin);
#define  P7_MODE_OUT_PP(Pin)   P7M1 &= ~(Pin), P7M0 |= (Pin);

//========================================================================
//                         端口内部4.1K上拉设置
//========================================================================
//上拉使能
#define P0_PULL_UP_ENABLE(Pin)  P0PU |= (Pin)
#define P1_PULL_UP_ENABLE(Pin)  P1PU |= (Pin)
#define P2_PULL_UP_ENABLE(Pin)  P2PU |= (Pin)
#define P3_PULL_UP_ENABLE(Pin)  P3PU |= (Pin)
#define P4_PULL_UP_ENABLE(Pin)  P4PU |= (Pin)
#define P5_PULL_UP_ENABLE(Pin)  P5PU |= (Pin)
#define P6_PULL_UP_ENABLE(Pin)  P6PU |= (Pin)
#define P7_PULL_UP_ENABLE(Pin)  P7PU |= (Pin)
//上拉禁止
#define P0_PULL_UP_DISABLE(Pin)  P0PU &= ~(Pin)
#define P1_PULL_UP_DISABLE(Pin)  P1PU &= ~(Pin)
#define P2_PULL_UP_DISABLE(Pin)  P2PU &= ~(Pin)
#define P3_PULL_UP_DISABLE(Pin)  P3PU &= ~(Pin)
#define P4_PULL_UP_DISABLE(Pin)  P4PU &= ~(Pin)
#define P5_PULL_UP_DISABLE(Pin)  P5PU &= ~(Pin)
#define P6_PULL_UP_DISABLE(Pin)  P6PU &= ~(Pin)
#define P7_PULL_UP_DISABLE(Pin)  P7PU &= ~(Pin)
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

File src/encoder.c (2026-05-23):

/*---------------------------------------------------------------------*/
/* 旋转编码器驱动 - 平台无关逻辑层实现                                   */
/* 旋转方向在中断中判定并累积, 主循环处理按键消抖和事件生成                 */
/* 即使主循环延迟, 旋转方向也不会丢失                                     */
/*---------------------------------------------------------------------*/

#include "encoder.h"
#include "STC8G_H_Timer.h"

/*---------------------------------------------------------------------*/
/* 全局编码器实例                                                       */
/*---------------------------------------------------------------------*/

encoder_t __xdata g_encoder;

/*---------------------------------------------------------------------*/
/* GPIO 读取实现 (一次性读取全部引脚)                                    */
/*---------------------------------------------------------------------*/

uint8_t encoder_hal_read_pins(void)
{
    uint8_t pins = 0;
    if (ENC_PIN_A) pins |= ENC_MASK_A;
    if (ENC_PIN_B) pins |= ENC_MASK_B;
    if (ENC_PIN_BTN) pins |= ENC_MASK_BTN;
    return pins;
}

/*---------------------------------------------------------------------*/
/* Timer0 初始化 - 1ms 中断                                             */
/* STC8H Timer0 工作在 16位自动重载模式, 1T模式                          */
/*---------------------------------------------------------------------*/

/* Timer0 重载值计算: 65536 - (MAIN_Fosc / 1000) */
/* 1T模式下每个机器周期 = 1个时钟周期                                    */
#define TIMER0_RELOAD   (65536UL - (MAIN_Fosc / 1000UL))

void encoder_hal_init(void)
{
    /* 确保引脚为高电平(外部已有10K上拉) */
    ENC_PIN_A = 1;
    ENC_PIN_B = 1;
    ENC_PIN_BTN = 1;

    TIM_InitTypeDef __xdata time_def = {
        .TIM_Mode = TIM_16BitAutoReloadNoMask,
        .TIM_ClkSource = TIM_CLOCK_1T,
        .TIM_ClkOut = DISABLE,
        .TIM_Value = TIMER0_RELOAD,
        .TIM_PS = 0,
        .TIM_Run = ENABLE,
    };

    Timer_Inilize(Timer0, &time_def);
    TF0 = 1;  /* 清除 Timer0 溢出标志 */
    ET0 = 1;  /* 使能 Timer0 中断 */
}

/*---------------------------------------------------------------------*/
/* Timer0 中断服务函数 - 1ms 周期仅采样引脚                              */
/* 极轻量: 只读引脚并置标志位, 不做任何逻辑处理                           */
/*---------------------------------------------------------------------*/

INTERRUPT(Timer0_ISR_Handler, TMR0_VECTOR)
{
    encoder_sample();
}

/*---------------------------------------------------------------------*/
/* AB相正交编码方向判定 (纯位运算, 无需查找表)                            */
/*   顺时针: 00 -> 01 -> 11 -> 10 -> 00                                */
/*   逆时针: 00 -> 10 -> 11 -> 01 -> 00                                */
/* 方向公式: prev_A ^ curr_B                                            */
/*   结果为1 = 顺时针(+1), 结果为0 = 逆时针(-1)                         */
/*---------------------------------------------------------------------*/

/*---------------------------------------------------------------------*/
/* 初始化                                                               */
/*---------------------------------------------------------------------*/

void encoder_init(void)
{
    uint8_t __xdata pins, ab;

    /* 先初始化硬件 */
    encoder_hal_init();

    /* 读取当前AB相状态作为初始值 */
    pins = encoder_hal_read_pins();
    ab = (pins & ENC_MASK_AB);  /* 提取AB相: (A<<1)|B */

    /* 初始化中断区: ab_prev=ab, 无按键采样标志 */
    g_encoder.isr_state = ab;
    g_encoder.rot_delta = 0;

    /* 主循环区清零 */
    g_encoder.btn_state = 0;
    g_encoder.btn_filter = 0;
    g_encoder.btn_hold = 0;
    g_encoder.events = ENCODER_EVT_NONE;
}

/*---------------------------------------------------------------------*/
/* 中断采样函数 (在定时器中断中调用, 建议周期1ms)                         */
/* 完成: 旋转方向判定+累积, 按键引脚采样                                  */
/* 8051上约15条指令, 执行时间 < 8us @24MHz                                */
/*---------------------------------------------------------------------*/

void encoder_sample(void)
{
    uint8_t __xdata pins, ab_curr, ist;

    ist = g_encoder.isr_state;
    pins = encoder_hal_read_pins();

    /* 提取AB相: (A<<1)|B */
    ab_curr = (pins & ENC_MASK_AB);

    if (ab_curr != (ist & ENC_MASK_AB)) {
        /* AB相发生变化, 判定方向并累积增量 */
        /* prev_A(bit1) ^ curr_B(bit0): 1=CW, 0=CCW */
        if (((ist >> 1) ^ ab_curr) & ENC_MASK_B) {
            g_encoder.rot_delta++;
        } else {
            g_encoder.rot_delta--;
        }
        /* 更新 ab_prev, 保留其余位 */
        ist = (ist & ~ENC_MASK_AB) | ab_curr;
    }

    /* 采样按键引脚, 存入 ENC_MASK_BTN, 置就绪标志 */
    ist = (ist & ~ENC_MASK_BTN) | (pins & ENC_MASK_BTN);
    g_encoder.isr_state = ENC_ISR_BTN_FLAG | ist;
}

/*---------------------------------------------------------------------*/
/* 主循环处理函数 (在主循环中调用, 不占用中断时间)                         */
/*---------------------------------------------------------------------*/

void encoder_process(void)
{
    int8_t __xdata delta;
    uint8_t __xdata ist, bs;

    /*--- 旋转事件: 消费中断累积的增量 ---*/
    delta = g_encoder.rot_delta;
    if (delta >= ENCODER_ROT_DELTA || delta <= - ENCODER_ROT_DELTA) {
        g_encoder.rot_delta = 0;    /* 清零 (极短窗口内可能丢失1步, 可接受) */
        if (delta > 0) {
            g_encoder.events |= ENCODER_EVT_CW;
        } else {
            g_encoder.events |= ENCODER_EVT_CCW;
        }
    }

    /*--- 按键处理: 消费中断采样的引脚值 ---*/
    ist = g_encoder.isr_state;
    if (!(ist & ENC_ISR_BTN_FLAG)) {
        return;
    }
    g_encoder.isr_state = ist & ~ENC_ISR_BTN_FLAG;   /* 清除就绪标志 */

    bs = g_encoder.btn_state;

    /* E引脚低电平有效: pin=0表示按下 */
    /* 将引脚值(bit0)取反后左移到bit1位置, 与btn_state(bit1)比较 */
    if ((((~ist & ENC_MASK_BTN) >> (ENC_MASK_BTN_SHIFT - 1)) ^ bs) & ENC_BTN_STATE) {
        /* 状态不一致, 累加滤波计数 */
        g_encoder.btn_filter++;
        if (g_encoder.btn_filter >= ENCODER_BTN_DEBOUNCE) {
            g_encoder.btn_filter = 0;
            bs ^= ENC_BTN_STATE;            /* 翻转按键状态 */
            bs &= ~ENC_BTN_LONG;            /* 清除长按标志 */
            g_encoder.events |= (bs & ENC_BTN_STATE) ? ENCODER_EVT_BTN_DOWN
                                                : ((g_encoder.btn_hold >= ENCODER_BTN_LONG_PRESS)
                                                   ? ENCODER_EVT_BTN_LONG_UP
                                                   : ENCODER_EVT_BTN_UP);
            g_encoder.btn_hold = 0;
        }
    } else {
        g_encoder.btn_filter = 0;
    }

    /* 长按检测 */
    if ((bs & ENC_BTN_STATE) && !(bs & ENC_BTN_LONG)) {
        g_encoder.btn_hold++;
        if (g_encoder.btn_hold >= ENCODER_BTN_LONG_PRESS) {
            g_encoder.events |= ENCODER_EVT_BTN_LONG;
            bs |= ENC_BTN_LONG;
        }
    }

    g_encoder.btn_state = bs;
}

/*---------------------------------------------------------------------*/
/* 提取并清除事件                                                       */
/*---------------------------------------------------------------------*/

uint8_t encoder_poll_event(void)
{
    uint8_t __xdata evt;
    evt = g_encoder.events;
    g_encoder.events = ENCODER_EVT_NONE;
    return evt;
}

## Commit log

2026-05-23 init: 初始化仓库
    [BoxFront.STL, BoxMain.STL, Btn.STL]
2026-06-14 chore: 增加LICENSE说明
2026-06-14 chore: 增加成品展示图
2026-06-14 fix: 重复图片
2026-06-19 chore: 使用step文件
    [BoxFront.STEP, BoxFront.STL, BoxMain.STL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]
2026-06-19 fix: 初始频率调整
2026-06-19 chore: 启动发送uart
